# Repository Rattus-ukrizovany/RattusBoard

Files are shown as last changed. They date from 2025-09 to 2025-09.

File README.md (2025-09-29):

# 🐭 RattusBoard

<div align="center">

*A premium VIAL-powered split ergonomic keyboard with integrated trackball and encoder*






### 📸 **Showcase**

<table>
<tr>
<td width="50%" align="center">

**Left Half**
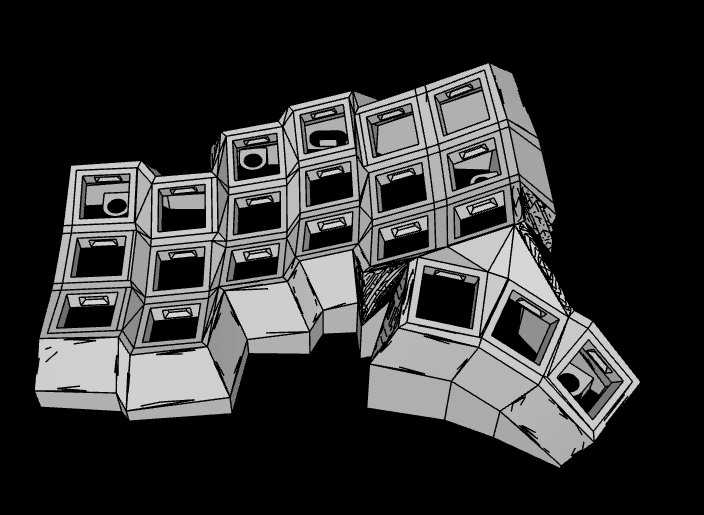
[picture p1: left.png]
RattusBoard Left Half


</td>
<td width="50%" align="center">

**Right Half**
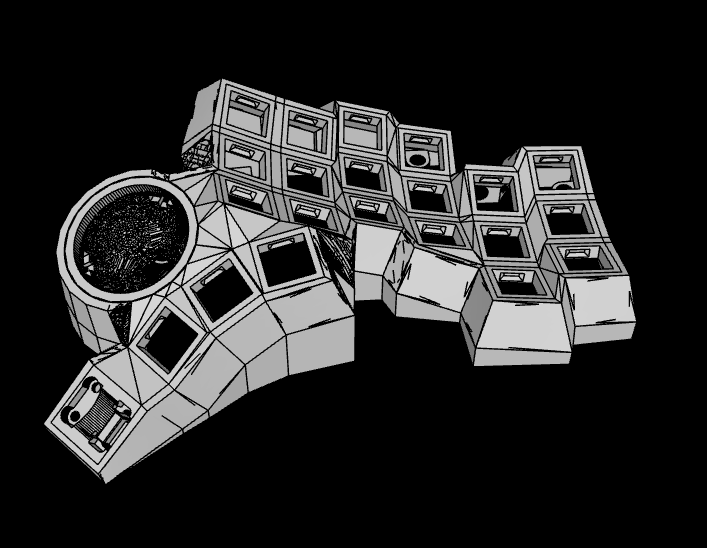
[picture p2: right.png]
RattusBoard Right Half


</td>
</tr>
</table>

</div>

---

## 🚀 Quick Start

<table>
<tr>
<td width="33%">

### 👤 **New Users**
Just want to build and use?
- 📥 **[Download Latest Firmware](https://github.com/Rattus-ukrizovany/RattusBoard/releases/latest/download/rattusboard_vial.uf2)**
- 🔧 **[Flash Instructions](#-firmware-flashing--split-setup)**
- 🏗️ **[Build Guide](HALVES_WIRING.md)**

</td>
<td width="33%">

### ⚙️ **Customizers**
Want to modify layouts?
- 🎹 **[Vial App](https://get.vial.today/)** (Live editing)
- 📝 **[Default Keymap](keyboards/rattusboard/keymaps/default/keymap.c)**
- 🔑 **[Layer Documentation](#-keymap--layers)**

</td>
<td width="33%">

### 🧑‍💻 **Developers**
Building from source?
- ⚡ **[QMK Setup Guide](QMK_SETUP.md)**
- 🔧 **[Config Files](keyboards/rattusboard/)**
- 🐞 **[Troubleshooting](#-troubleshooting-reference)**

</td>
</tr>
</table>

### 📚 **Essential Links**
- 🔌 **[Wiring & Pinout Guide](HALVES_WIRING.md)** — Complete build instructions with diagrams
- 💬 **[Get Help](https://github.com/Rattus-ukrizovany/RattusBoard/issues/new/choose)** — Report bugs, ask questions, request features

---

## 🌟 Overview

<div align="center">

**RattusBoard** is a cutting-edge split ergonomic keyboard designed for productivity enthusiasts and professionals who demand precision, comfort, and customization.

*Built on the robust QMK firmware for the RP2040 platform, featuring integrated trackball, rotary encoder, and real-time keymap editing via Vial.*

</div>

### ✨ Key Features

<table>
<tr>
<td width="50%">

#### 🎯 **Hardware**
- 🖱️ **PMW3360 Trackball** — Precision cursor control
- 🔄 **Rotary Encoder** — Smooth, customizable input  
- ⌨️ **Split Design** — Based on Corne layout
- 🔌 **USB-C** — Raspberry Pi Pico (RP2040)
- 🔗 **TRRS Connection** — Between halves

</td>
<td width="50%">

#### ⚡ **Software**
- 🎹 **Vial Support** — Real-time editing (no reflashing!)
- 📱 **QMK Firmware** — Layers, macros, advanced features
- 🔧 **Auto Hand Detection** — Single firmware for both halves
- 🌐 **Open Source** — GPL v3, fully customizable

</td>
</tr>
</table>

---

## 📋 Hardware Specifications

<table>
<tr>
<td width="50%">

### 🖥️ **Controller & Matrix**
- **MCU:** Raspberry Pi Pico (RP2040)
- **Layout:** Split 3×6 + 3 thumbs (42 keys total)
- **Matrix:** 4×6 per half (unified pin mapping)
- **Diode Direction:** COL2ROW
- **Debounce:** 5ms

### 🔌 **Pin Configuration**
- **Matrix Rows:** GP2, GP3, GP4, GP5
- **Matrix Cols:** GP15, GP16, GP17, GP18, GP19, GP20
- **Split Serial:** GP1 (TRRS communication)
- **Hand Detection:** GP21 (GND=Left, Float=Right)

</td>
<td width="50%">

### 🖱️ **Peripherals (Right Half)**
- **Trackball:** PMW3360 sensor @ 1600 CPI
- **SPI Pins:** CS=GP22, SCK=GP23, MOSI=GP24, MISO=GP25
- **Encoder:** GP26 (A), GP27 (B), 4 detents/rotation

### ⚡ **Features**
- **Bootmagic:** Enabled
- **NKRO:** Full N-key rollover
- **Mouse Keys:** Enabled
- **Pointing Device:** PMW3360 driver
- **Dynamic Layers:** 8 layers supported
- **Vial UID:** `{0x12, 0x34, 0x56, 0x78, 0x90, 0x12, 0x34, 0xEF}`

</td>
</tr>
</table>

> 📖 **For detailed pin assignments and wiring diagrams, see [HALVES_WIRING.md](HALVES_WIRING.md)**

---

## 🛠️ Build Guide

<div align="center">

### 📝 **Build Process Overview**

</div>

```mermaid
graph LR
    A[📋 Parts] --> B[🔌 Wiring]
    B --> C[⚡ Testing]
    C --> D[🚀 Firmware]
    D --> E[🎉 Complete!]
```

<table>
<tr>
<td width="50%">

### 🔧 **Required Skills**
- ✅ Basic soldering (THT components)
- ✅ Wire management
- ✅ Following wiring diagrams
- ✅ Basic troubleshooting

### 📦 **Required Components**
- 2× Raspberry Pi Pico
- 2× Sets of switches & keycaps  
- 1× PMW3360 trackball module
- 1× Rotary encoder
- Various resistors, diodes, wiring

</td>
<td width="50%">

### 📚 **Build Resources**
- 🔌 **[Complete Wiring Guide](HALVES_WIRING.md)**
- 📊 **[Pin Assignment Table](HALVES_WIRING.md#-pin-assignment-summary)**
- 🔍 **[Assembly Tips](HALVES_WIRING.md#️-best-practices--tips)**
- 🐞 **[Hardware Troubleshooting](HALVES_WIRING.md#-troubleshooting)**

### ⏱️ **Build Time**
- **Beginner:** 6-8 hours
- **Experienced:** 3-4 hours

</td>
</tr>
</table>

> 💡 **Pro Tip:** Each half uses independent matrix wiring with GP21 pin for automatic hand detection. No need for separate left/right firmware!

---

## 🚀 Firmware Flashing & Split Setup

<div align="center">

### 🎯 **Key Point: One Firmware File for Both Halves!**

**No need for separate left/right firmware files — RattusBoard uses automatic hand detection.**

</div>

### ⚡ **Quick Flash Guide**

<table>
<tr>
<td width="50%">

#### 📥 **Step 1: Download**
1. Go to **[Latest Release](https://github.com/Rattus-ukrizovany/RattusBoard/releases/latest)**
2. Download **`rattusboard_vial.uf2`**

#### 🔧 **Step 2: Flash Both Halves**
1. Hold **BOOTSEL** + plug USB (Pico enters bootloader)
2. Drag **`rattusboard_vial.uf2`** to **RPI-RP2** drive
3. Repeat for **both Picos** with the **same file**

</td>
<td width="50%">

#### 🔗 **Step 3: Connect & Test**
1. Connect halves with **TRRS cable**
2. Plug USB into **left half** (master)
3. Both halves should work automatically ✨

#### 🎹 **Step 4: Customize (Optional)**
- Download **[Vial App](https://get.vial.today/)**
- Live edit keymap without reflashing!

</td>
</tr>
</table>

### 🧠 **How Auto Hand Detection Works**

```
Left Half (Master)          Right Half (Slave)
┌─────────────────┐        ┌─────────────────┐
│ GP21 → GND      │◀─TRRS─▶│ GP21 → Float    │
│ (Detected Left) │        │ (Detected Right)│
│                 │        │                 │
│ • Matrix 4×6    │        │ • Matrix 4×6    │
│ • USB Master    │        │ • Trackball     │
│                 │        │ • Encoder       │
└─────────────────┘        └─────────────────┘
```

> 🔬 **Technical Details:** The firmware reads GP21 on boot. If grounded, it configures as left/master. If floating, it configures as right/slave with trackball/encoder enabled.

### 🛠️ **Advanced Options**

<details>
<summary><strong>🧑‍💻 For Developers: Custom Builds</strong></summary>

- **QMK Build:** See [QMK_SETUP.md](QMK_SETUP.md) for building from source
- **Custom Features:** The single firmware approach works for most users
- **Separate Builds:** Only needed for experimental features

```bash
# Build VIAL firmware (what gets released)
qmk compile -kb rattusboard -km vial
```

</details>

### 🚨 **Troubleshooting Flash Issues**

| **Problem** | **Solution** |
|---|---|
| Pico not detected | Try different USB cable, ensure BOOTSEL pressed during connection |
| Only one half works | Check TRRS wiring, verify both halves flashed with same firmware |
| No trackball/encoder | Ensure components wired to right half, check SPI connections |
| Keys not working | Test matrix wiring, use [keyboard tester](https://www.keyboardtester.com/) |

---

## 🎹 Keymap & Layers

<div align="center">

### 🗝️ **4-Layer Layout Based on Corne**

*Optimized for productivity with integrated trackball and encoder controls*

</div>

<table>
<tr>
<td width="50%">

### 📋 **Default Layers**
- **Layer 0:** Base QWERTY layout
- **Layer 1:** Numbers & symbols (raise)
- **Layer 2:** Navigation & function keys (lower) 
- **Layer 3:** Media, system, & trackball controls

### 🖱️ **Trackball Integration**
- **Cursor Movement:** Always active on right half
- **Click Actions:** Thumb keys for left/right click
- **Scroll Mode:** Encoder for precise scrolling

</td>
<td width="50%">

### 🎛️ **Live Customization**
- **[Download Vial](https://get.vial.today/)** for real-time editing
- **No Reflashing:** Changes apply instantly
- **8 Layers Available:** Expand beyond defaults

### 📚 **Resources**
- **[Default Keymap Source](keyboards/rattusboard/keymaps/default/keymap.c)**
- **[Vial Keymap Source](keyboards/rattusboard/keymaps/vial/keymap.c)**
- **[Pin Mappings](HALVES_WIRING.md)**

</td>
</tr>
</table>

### 🔧 **Encoder Functions**

| **Layer** | **Encoder Action** | **Description** |
|---|---|---|
| **Base** | Volume Up/Down | System volume control |
| **Raise** | Browser Back/Forward | Web navigation |
| **Lower** | Undo/Redo | Text editing shortcuts |
| **Media** | Track Previous/Next | Media player control |

> 💡 **Tip:** The encoder is located on the right half and can be customized per layer using Vial!

---

## 💻 Software Support

<table>
<tr>
<td width="50%">

### 🎹 **Vial Support** *(Recommended)*
- ✅ **Pre-configured** — Works out-of-the-box
- ⚡ **Live Editing** — No reflashing required
- 🎛️ **Full Control** — Layers, macros, rotary encoder
- 📱 **Cross-Platform** — Windows, macOS, Linux

**Get Started:**
1. Download [Vial App](https://get.vial.today/)
2. Connect RattusBoard
3. Start customizing! 🎨

</td>
<td width="50%">

### ⚙️ **QMK Support** *(Advanced)*
- 🔧 **Custom Builds** — Full source code access
- 🧪 **Experimental Features** — Bleeding edge QMK
- 🛠️ **Advanced Config** — Low-level customization

**Quick Build:**
```bash
# Clone VIAL-QMK for compatibility
git clone https://github.com/vial-kb/vial-qmk.git
cd vial-qmk
qmk compile -kb rattusboard -km vial
```

</td>
</tr>
</table>

### 📖 **Documentation Links**
- 📚 **[QMK Documentation](https://docs.qmk.fm/)** — Official QMK guides and reference
- 🎹 **[Vial Documentation](https://get.vial.today/docs/)** — Vial-specific features and setup
- 🔧 **[RattusBoard QMK Setup](QMK_SETUP.md)** — Detailed build instructions

---

## ⚡ Firmware Downloads

<div align="center">

### 📥 **Latest Release**

**[Download rattusboard_vial.uf2](https://github.com/Rattus-ukrizovany/RattusBoard/releases/latest/download/rattusboard_vial.uf2)**

*VIAL-enabled firmware with all features — works for both halves!*



</div>

### 📋 **What's Included**

<table>
<tr>
<td width="50%">

#### ✅ **Features**
- 🎹 **Vial Support** — Live keymap editing
- 🖱️ **PMW3360 Trackball** — Right half integration
- 🔄 **Rotary Encoder** — Scroll wheel functionality  
- ⚡ **Auto Hand Detection** — Single file, both halves
- 🔧 **All QMK Features** — NKRO, layers, macros

</td>
<td width="50%">

#### 🔢 **Technical Details**
- **Firmware Version:** Based on VIAL-QMK
- **File Size:** ~500KB typical
- **Compatibility:** RP2040 (Raspberry Pi Pico)
- **Build:** Automated via GitHub Actions
- **Verified:** Tested on real hardware

</td>
</tr>
</table>

### ⚠️ **Important Notes**

> 🎯 **Single Firmware Approach:** Do NOT download separate left/right files for typical use. The unified firmware automatically detects which half it's running on.

> 🔄 **Always Use Latest:** Older releases may have bugs or missing features. Always download from the link above for the best experience.

### 📦 **Alternative Downloads**
- **[All Releases](https://github.com/Rattus-ukrizovany/RattusBoard/releases)** — Previous versions and release notes
- **[Build Artifacts](https://github.com/Rattus-ukrizovany/RattusBoard/actions)** — Development builds (require GitHub login)

---

## 🧪 Troubleshooting Reference

<div align="center">

### 🔍 **Common Issues & Solutions**

*Most problems can be resolved with one of these fixes*

</div>

### 🚨 **Hardware Issues**

<table>
<tr>
<th width="30%">Problem</th>
<th width="70%">Solution</th>
</tr>
<tr>
<td>🔌 <strong>Pico not detected</strong></td>
<td>
• Try a different USB cable (data, not just power)<br>
• Ensure BOOTSEL button is held <em>while</em> plugging in USB<br>
• Check USB port on computer<br>
• Use USB 2.0 port if USB 3.0 causes issues
</td>
</tr>
<tr>
<td>⌨️ <strong>Only one half works</strong></td>
<td>
• Check TRRS cable and 3.5mm jacks<br>
• Verify both halves flashed with <strong>same</strong> firmware file<br>
• Test TRRS cable with multimeter<br>
• Ensure GP1 (serial) and power connections solid
</td>
</tr>
<tr>
<td>🔤 <strong>Keys not registering</strong></td>
<td>
• Check matrix wiring against <a href="HALVES_WIRING.md">pin diagram</a><br>
• Test individual keys with <a href="https://www.keyboardtester.com/">keyboard tester</a><br>
• Verify diode orientation (COL2ROW)<br>
• Check solder joints on switches
</td>
</tr>
<tr>
<td>🖱️ <strong>Trackball/encoder issues</strong></td>
<td>
• Ensure components are on <strong>right half only</strong><br>
• Check SPI wiring: CS=GP22, SCK=GP23, MOSI=GP24, MISO=GP25<br>
• Clean trackball sensor with compressed air<br>
• Verify encoder pins: A=GP26, B=GP27
</td>
</tr>
</table>

### 💻 **Software Issues**

<table>
<tr>
<th width="30%">Problem</th>
<th width="70%">Solution</th>
</tr>
<tr>
<td>🎹 <strong>Vial not detecting</strong></td>
<td>
• Ensure you flashed <code>rattusboard_vial.uf2</code> (VIAL-enabled)<br>
• Restart Vial application<br>
• Try a different USB port<br>
• Check Windows drivers (may need Zadig)
</td>
</tr>
<tr>
<td>⌨️ <strong>Wrong layout active</strong></td>
<td>
• Press layer switching keys (thumb cluster)<br>
• Check current layer in Vial app<br>
• Reset to defaults in Vial<br>
• Re-flash firmware if needed
</td>
</tr>
<tr>
<td>🔧 <strong>Build failures</strong></td>
<td>
• Follow <a href="QMK_SETUP.md">QMK Setup Guide</a> exactly<br>
• Use VIAL-QMK repository (not main QMK)<br>
• Update QMK CLI: <code>pip install -U qmk</code><br>
• Clean build: remove <code>.build</code> directory
</td>
</tr>
</table>

### 🛠️ **Advanced Diagnostics**

<details>
<summary><strong>🔬 Enable Debug Output</strong></summary>

Add to your `config.h` for debugging:
```c
#define DEBUG_ENABLE
#define DEBUG_MATRIX
#define DEBUG_KEYBOARD
```

Then use QMK Toolbox or serial console to view debug output.
</details>

<details>
<summary><strong>🧪 Hardware Testing</strong></summary>

- **Matrix Test:** Each key should register in Vial or keyboard tester
- **Continuity Test:** Use multimeter to verify all connections
- **Power Test:** Both halves should light up when connected
- **SPI Test:** Trackball should move cursor when rolled
</details>

### 💬 **Still Need Help?**

<div align="center">

**[Open an Issue](https://github.com/Rattus-ukrizovany/RattusBoard/issues/new/choose)** with:
- 📸 Photos of your build
- 📋 Detailed problem description  
- 🔧 What you've already tried
- 💻 Computer OS and Vial version

*We're here to help! 🤝*

</div>

---

## 🤝 Contributing

<div align="center">

### 🌟 **Help Make RattusBoard Better!**

*We welcome contributions from makers, coders, and keyboard enthusiasts*

</div>

<table>
<tr>
<td width="33%">

### 🐛 **Report Issues**
- 🔍 Found a bug?
- 💡 Have a feature idea?
- 📖 Documentation unclear?

**[Create an Issue](https://github.com/Rattus-ukrizovany/RattusBoard/issues/new/choose)**

</td>
<td width="33%">

### 🛠️ **Code Contributions**
- 🔧 Firmware improvements
- 🖥️ Tooling enhancements  
- 📚 Documentation updates
- 🧪 Testing & validation

**[Submit a PR](https://github.com/Rattus-ukrizovany/RattusBoard/pulls)**

</td>
<td width="33%">

### 📸 **Community**
- 🏗️ Share your build photos
- 💭 Discuss modifications
- 🎯 Help other builders
- 🔧 Share custom layouts

**[Join Discussions](https://github.com/Rattus-ukrizovany/RattusBoard/discussions)**

</td>
</tr>
</table>

### 📋 **Ways to Contribute**
- ✅ Test firmware on new hardware revisions
- ✅ Improve build documentation with photos
- ✅ Create video tutorials or build guides  
- ✅ Port to other microcontrollers
- ✅ Design case/enclosure modifications
- ✅ Optimize QMK configuration

> 💡 **New to contributing?** Check out [CONTRIBUTING.md](CONTRIBUTING.md) for detailed guidelines.

---

## 📜 License

This project is licensed under **GNU General Public License v3.0** — see [LICENSE](LICENSE) for details.

<details>
<summary><strong>📋 What this means</strong></summary>

- ✅ **Free to use** — Personal and commercial use allowed
- ✅ **Open source** — Full source code available
- ✅ **Modify freely** — Make your own improvements
- ✅ **Share modifications** — But must remain open source
- ❌ **No warranty** — Use at your own risk

</details>

---

## 🙏 Acknowledgments

<div align="center">

### 💖 **Special Thanks**

</div>

<table>
<tr>
<td width="50%">

#### 🌟 **Communities**
- **[QMK Firmware](https://qmk.fm/)** — Powerful keyboard firmware
- **[Vial](https://get.vial.today/)** — Real-time keymap editing
- **[Corne Keyboard](https://github.com/foostan/crkbd)** — Layout inspiration
- **[RP2040 Community](https://www.raspberrypi.org/products/raspberry-pi-pico/)** — Hardware platform

</td>
<td width="50%">

#### 🛠️ **Tools & Libraries**
- **PMW3360 Drivers** — Precise trackball control
- **GitHub Actions** — Automated firmware builds
- **ARM GCC Toolchain** — Cross-compilation
- **Python QMK CLI** — Build system

</td>
</tr>
</table>

<div align="center">

---

**🐭 Made with ❤️ by the keyboard community**

*Happy typing, and may your keys always register! ⌨️✨*

Star History Chart (https://star-history.com/#Rattus-ukrizovany/RattusBoard&Date)

</div>

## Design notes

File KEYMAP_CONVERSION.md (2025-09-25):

# RattusBoard Keymap Conversion from ZMK

This document describes the keymap conversion from the original ZMK configuration to QMK format.

## Original ZMK Source
The keymap was converted from: [corne-zmk-config](https://github.com/Rattus-ukrizovany/corne-zmk-config)

## Layer Structure Changes

| ZMK Layer | QMK Layer | Description |
|---|---|---|
| `DEFAULT_L` (0) | `_DEFAULT` (0) | Base QWERTY layer |
| `SYMBOLS_L` (1) | `_SYMBOLS` (1) | Numbers and symbols (left thumb) |
| `ARROWS_L` (2) | `_ARROWS` (2) | F-keys, media, navigation (right thumb) |
| `NUMBERS_L` (3) | `_NUMBERS` (3) | Additional layer via layer-tap on Enter |
| Flash (conditional) | `_ADJUST` (4) | System controls, trackball, mouse |

## Key Differences

### Base Layer (_DEFAULT)
- **ZMK**: TAB, LEFT_SHIFT, LEFT_CONTROL modifiers
- **QMK**: Matches exactly - `KC_TAB`, `KC_LSFT`, `KC_LCTL`

### Layer Activation
- **ZMK**: `&mo 1` (Symbols), `&mo 2` (Arrows), `&lt 3 ENTER` (Numbers)
- **QMK**: `SYMBOLS`, `ARROWS`, `LT(_NUMBERS, KC_ENT)`

### System Controls
- **ZMK**: `&bt BT_CLR_ALL`, `&sys_reset`, `&bootloader`
- **QMK**: `QK_BOOT` (unified reset functionality)

### Encoder Configuration
Enhanced encoder support with layer-specific functions:
- **_DEFAULT**: Scroll wheel (up/down)
- **_SYMBOLS**: Volume control
- **_ARROWS**: Horizontal scroll
- **_NUMBERS**: Page up/down
- **_ADJUST**: Brightness control

## Features Retained

- ✅ Split keyboard functionality
- ✅ PMW3360 trackball integration
- ✅ Rotary encoder support
- ✅ Vial compatibility
- ✅ All original key assignments
- ✅ Layer logic and activation patterns

## Build Instructions

```bash
# Compile firmware
qmk compile -kb rattusboard -km default

# The build produces a single .uf2 file that works on both halves
# Thanks to hardware hand detection via GP21 pin
```

## Notes

- No changes needed to hardware wiring
- Single firmware file works for both halves (hardware auto-detection)
- Vial configuration remains compatible
- All trackball and encoder features preserved

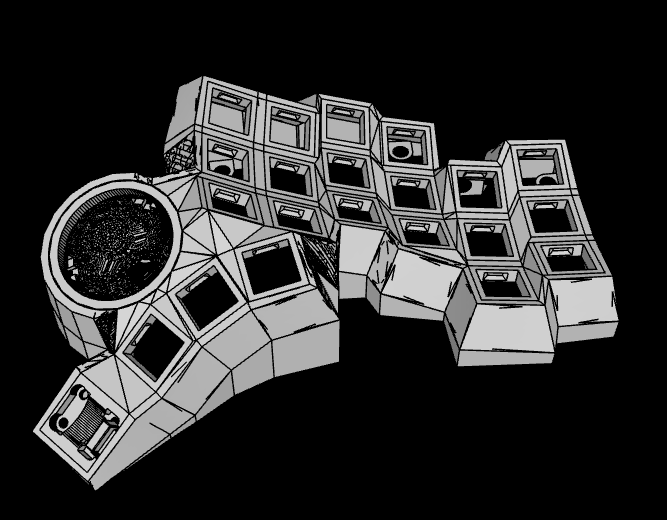
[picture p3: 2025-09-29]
models/image.png

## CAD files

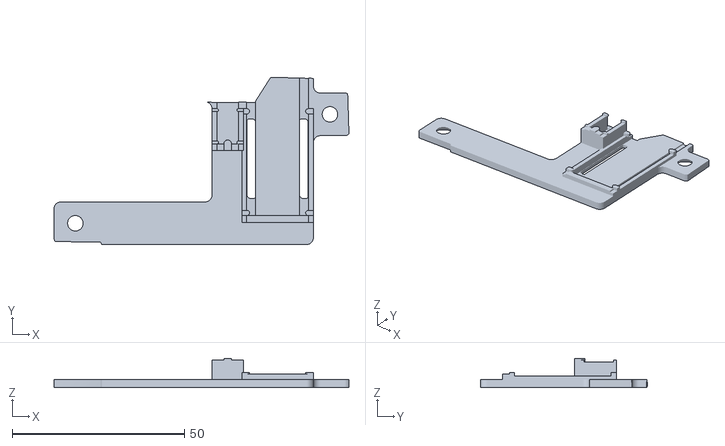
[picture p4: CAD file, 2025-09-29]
Models/rattus-board-holderright.stl
85.6 x 48.6 x 8.50

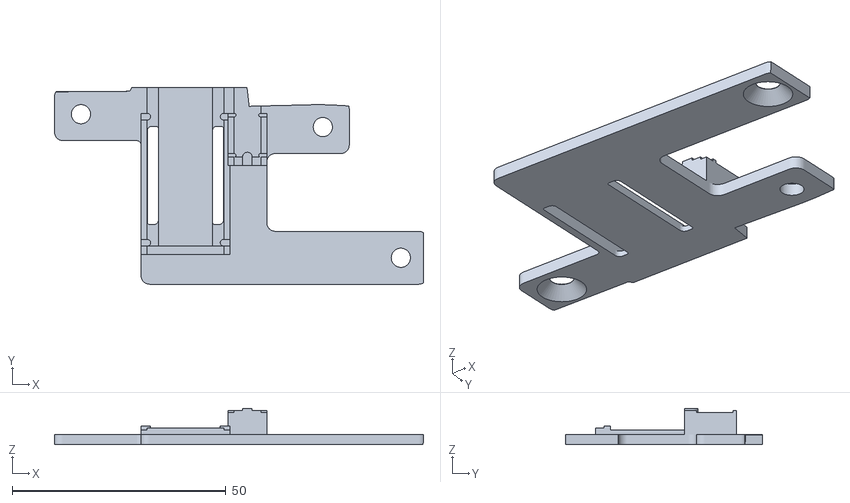
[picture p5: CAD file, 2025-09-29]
Models/rattus-board-holderleft.stl
86.4 x 46.0 x 8.50

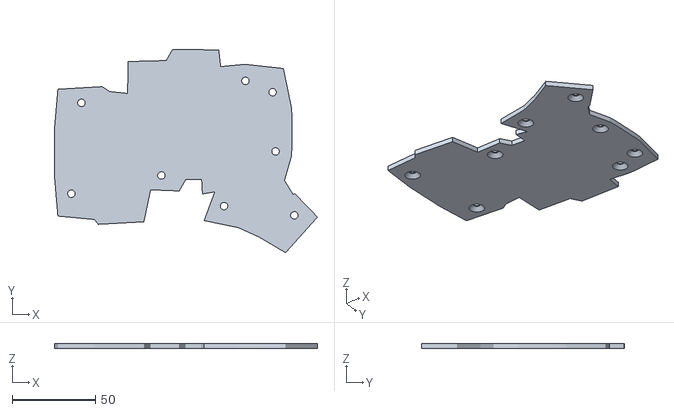
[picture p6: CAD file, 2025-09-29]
Models/rattus-board-plateleft.stl
158.2 x 122.3 x 3.00

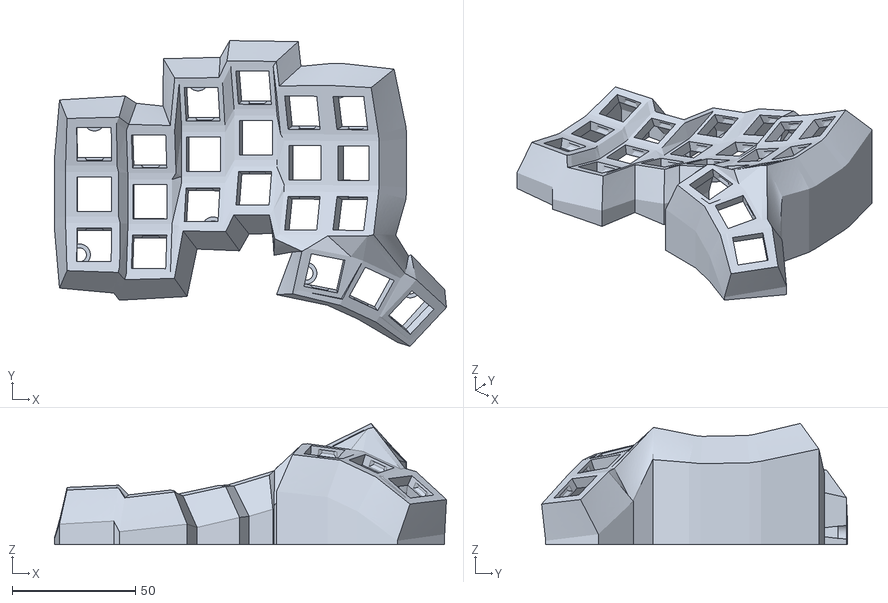
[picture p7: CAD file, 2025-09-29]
Models/rattus-board-caseleft.stl
158.9 x 124.0 x 49.1

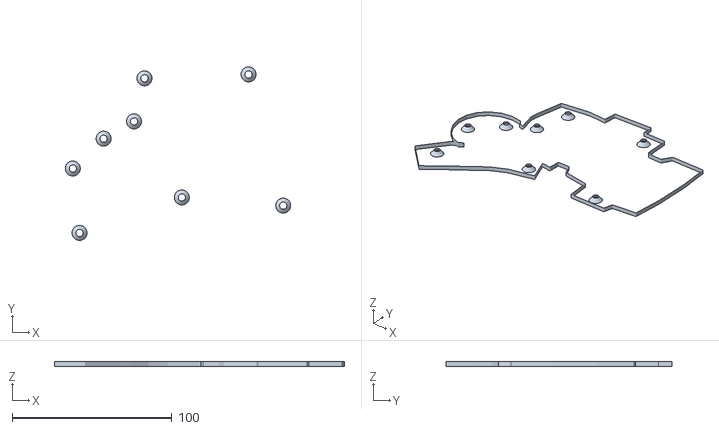
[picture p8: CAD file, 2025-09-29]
Models/rattus-board-plateright.stl
181.8 x 141.8 x 3.00

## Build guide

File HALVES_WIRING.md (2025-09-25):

# 🔌 RattusBoard Split Keyboard Wiring Guide

*Detailed half-specific wiring instructions for the RattusBoard split ergonomic keyboard*

---

## Table of Contents

- [Overview Diagram](#-overview-diagram)
- [Left Half (Master) Wiring](#-left-half-master-wiring)
- [Right Half (Slave) Wiring](#-right-half-slave-wiring)
- [Critical Assembly Guidelines](#-critical-assembly-guidelines)
- [Assembly & Testing Tips](#-assembly--testing-tips)
- [Pin Assignment Summary](#-pin-assignment-summary)
- [Troubleshooting](#-troubleshooting)

---

## 🔍 Overview Diagram

```
Left Half (Master)                    Right Half (Slave)
┌─────────────────────┐              ┌─────────────────────┐
│    [USB-C INPUT]    │              │                     │
│  Raspberry Pi Pico  │◄─── TRRS ───►│  Raspberry Pi Pico  │
│                     │              │                     │
│  MATRIX 4×6         │              │  MATRIX 4×6         │
│  Cols: GP15-GP20    │              │  Cols: GP15-GP20    │
│  Rows: GP2-GP5      │              │  Rows: GP2-GP5      │
│                     │              │                     │
│  Split Pin: GP21→GND│              │  Split Pin: GP21    │
│  TRRS: GP1          │              │  TRRS: GP1          │
│                     │              │                     │
│                     │              │  [PMW3360 SENSOR]   │
│                     │              │  SPI: GP22-GP25     │
│                     │              │                     │
│                     │              │  [ROTARY ENCODER]   │
│                     │              │  Pins: GP26-GP27    │
└─────────────────────┘              └─────────────────────┘
        MASTER                              SLAVE
     (USB Connected)                    (TRRS Powered)
```

**NEW MATRIX DESIGN:**
- **Unified 4×6 Matrix per half** - 3 main rows + 1 thumb row
- **Same pin assignments** - Both halves use identical pins: GP15-GP20 for columns
- **42 Total Keys** - 21 per half  
- **Thumb Cluster**: Left (cols 3,4,5), Right (cols 0,1,2)
- **TRRS Communication** - Only for coordination between halves via GP1

**Signal Flow:**
```
Computer ──USB-C──► Left Pico ──TRRS──► Right Pico
                        │                    │
                   Matrix 4×6           Matrix 4×6
                 (Independent)        (Independent)
                                           │
                                    ┌─────────────┐
                                    │ PMW3360     │
                                    │ Trackball   │
                                    └─────────────┘
                                           │
                                    ┌─────────────┐
                                    │ Rotary      │
                                    │ Encoder     │
                                    └─────────────┘
```

---

## 📍 Left Half (Master) Wiring

The left half serves as the master controller, connecting directly to your computer via USB-C and powering both halves through the TRRS connection.

### ⚡ Power & Communication

**USB-C Connection:**
```
┌─────────────────┐
│    USB-C Port   │ ──► Connect to Pico's native USB
│   (Computer)    │
└─────────────────┘
            │
    ┌─────────────────┐
    │ Raspberry Pi    │
    │ Pico (Left)     │
    │ GP25 ────► LED  │ (Optional status indicator)
    └─────────────────┘
```

**TRRS Jack Wiring:**
```
TRRS Jack          Raspberry Pi Pico
┌─────────┐       ┌─────────────────┐
│ Tip     │◄─────►│ GP1 (Serial)    │
│ Ring 1  │◄─────►│ GND (Ground)    │
│ Ring 2  │◄─────►│ 3.3V (Power)    │
│ Sleeve  │       │ NC (Unused)     │
└─────────┘       └─────────────────┘
```

### 🎯 Matrix Connections

**New 4×6 Matrix Layout (Left Half):**
```
    Switch Matrix Layout (Left Half)
    
    Col 0   Col 1   Col 2   Col 3   Col 4   Col 5
Row 0  ⊞  ──  ⊞  ──  ⊞  ──  ⊞  ──  ⊞  ──  ⊞     GP2
       │      │      │      │      │      │  
Row 1  ⊞  ──  ⊞  ──  ⊞  ──  ⊞  ──  ⊞  ──  ⊞     GP3
       │      │      │      │      │      │  
Row 2  ⊞  ──  ⊞  ──  ⊞  ──  ⊞  ──  ⊞  ──  ⊞     GP4
       │      │      │      │      │      │  
Row 3  ---    ---    ---    ⊞  ──  ⊞  ──  ⊞     GP5 (Thumb cluster)
       │      │      │      │      │      │  
      GP15   GP16   GP17   GP18   GP19   GP20
```

**Detailed Connections:**
```
Row 0: GP2  → All switches in top row (K00-K05)
Row 1: GP3  → All switches in second row (K10-K15)
Row 2: GP4  → All switches in third row (K20-K25)
Row 3: GP5  → Thumb cluster switches (K33, K34, K35)

Col 0: GP15 → All switches in column 0 (K00, K10, K20)
Col 1: GP16 → All switches in column 1 (K01, K11, K21)
Col 2: GP17 → All switches in column 2 (K02, K12, K22)
Col 3: GP18 → All switches in column 3 (K03, K13, K23, K33)
Col 4: GP19 → All switches in column 4 (K04, K14, K24, K34)
Col 5: GP20 → All switches in column 5 (K05, K15, K25, K35)
```

### 🔧 Critical Configuration

**Hand Detection (Essential!):**
```
GP21 ──┐
       │  Required for firmware to identify
       │  this half as the LEFT/MASTER
       └── GND
```

**Diode Installation:**
```
    For each switch position:
    
    Row Pin ←──┤|── Switch ──← Column Pin
                ▲
            Diode (1N4148)
         Cathode (band) toward row
         Anode toward column
    
    This is COL2ROW configuration
```

---

## 📍 Right Half (Slave) Wiring  

The right half operates as a slave, receiving power and communicating through the TRRS connection. It includes the trackball sensor and rotary encoder.

### ⚡ Power & Communication

**TRRS Jack Wiring (Mirror of left):**
```
TRRS Jack          Raspberry Pi Pico
┌─────────┐       ┌─────────────────┐
│ Tip     │◄─────►│ GP1 (Serial)    │
│ Ring 1  │◄─────►│ GND (Ground)    │
│ Ring 2  │◄─────►│ 3.3V (Power IN) │
│ Sleeve  │       │ NC (Unused)     │
└─────────┘       └─────────────────┘
```

**Power Flow Verification:**
```
Left Pico 3.3V ──TRRS──► Right Pico 3.3V
Left Pico GND  ──TRRS──► Right Pico GND
                │
                └──► Powers PMW3360 & Encoder
```

### 🎯 Matrix Connections

**New 4×6 Matrix Layout (Right Half):**
```
    Switch Matrix Layout (Right Half)
    
    Col 0   Col 1   Col 2   Col 3   Col 4   Col 5
Row 0  ⊞  ──  ⊞  ──  ⊞  ──  ⊞  ──  ⊞  ──  ⊞     GP2
       │      │      │      │      │      │  
Row 1  ⊞  ──  ⊞  ──  ⊞  ──  ⊞  ──  ⊞  ──  ⊞     GP3
       │      │      │      │      │      │  
Row 2  ⊞  ──  ⊞  ──  ⊞  ──  ⊞  ──  ⊞  ──  ⊞     GP4
       │      │      │      │      │      │  
Row 3  ⊞  ──  ⊞  ──  ⊞  ──  ---    ---    ---    GP5 (Thumb cluster)
       │      │      │      │      │      │  
      GP15   GP16   GP17   GP18   GP19   GP20
```

**Detailed Connections:**
```
Row 0: GP2  → All switches in top row (K06-K0B)
Row 1: GP3  → All switches in second row (K16-K1B)
Row 2: GP4  → All switches in third row (K26-K2B)
Row 3: GP5  → Thumb cluster switches (K30, K31, K32)

Col 0: GP15 → All switches in column 0 (K06, K16, K26, K30)
Col 1: GP16 → All switches in column 1 (K07, K17, K27, K31)
Col 2: GP17 → All switches in column 2 (K08, K18, K28, K32)
Col 3: GP18 → All switches in column 3 (K09, K19, K29)
Col 4: GP19 → All switches in column 4 (K0A, K1A, K2A)
Col 5: GP20 → All switches in column 5 (K0B, K1B, K2B)

```

### 🔧 Critical Configuration

**Hand Detection (Essential!):**
```
GP21 ────  (Leave unconnected/floating)
    
No connection to GND tells firmware
this is the RIGHT/SLAVE half
```

### 🖲️ PMW3360 Trackball Sensor

**SPI Interface Wiring:**
```
PMW3360 Module     Raspberry Pi Pico
┌─────────────┐   ┌─────────────────┐
│ VCC (3.3V)  │◄──│ 3.3V (from TRRS)│
│ GND         │◄──│ GND             │
│ CS          │◄──│ GP22            │
│ SCK         │◄──│ GP23            │
│ MOSI        │◄──│ GP24            │
│ MISO        │──►│ GP25            │
│ Motion      │──►│ GP28 (optional) │
│ Reset       │◄──│ 3.3V + 10kΩ res │
└─────────────┘   └─────────────────┘
```

**Physical Mounting:**
- Mount sensor on underside of PCB
- Ensure proper alignment with trackball
- Use adequate clearance for ball movement
- Clean lens before final assembly

### 🎛️ Rotary Encoder

**Quadrature Encoder Wiring:**
```
Encoder            Raspberry Pi Pico
┌─────────────┐   ┌─────────────────┐
│ A Phase     │◄──│ GP26            │
│ B Phase     │◄──│ GP27            │
│ Common      │◄──│ GND             │
│ Switch      │◄──│ GP28 (optional) │
│ Switch GND  │◄──│ GND             │
└─────────────┘   └─────────────────┘
```

**Encoder Types Supported:**
- EC11 rotary encoder (most common)
- 24-step resolution (configurable in firmware)
- Optional push-button functionality

---

## ⚡ Critical Assembly Guidelines

### 🔍 Pre-Assembly Inspection

**Component Verification:**
- [ ] 2× Raspberry Pi Pico controllers
- [ ] 1× PMW3360 trackball sensor module  
- [ ] 1× Rotary encoder (EC11 compatible)
- [ ] 42× MX-compatible switches
- [ ] 42× 1N4148 diodes
- [ ] 2× TRRS jacks (3.5mm, 4-conductor)
- [ ] 1× USB-C connector/breakout
- [ ] TRRS cable (4-conductor)
- [ ] Wiring supplies (28-30 AWG wire recommended)

### 🔧 Diode Installation

**Critical Polarity Requirements:**
```
COL2ROW Configuration:

Row ←─┤|──── Switch ────← Column
       ▲
   Diode band (cathode)
   points toward ROW

Correct:   Row ←─┤|──── Column
Incorrect: Row ─►|├──── Column
```

**Installation Tips:**
- Install diodes before switches for easier access
- Use consistent orientation across entire build
- Double-check polarity before soldering
- Trim leads after soldering to prevent shorts

### 🔌 TRRS System Requirements

**Cable Specifications:**
- **Type**: TRRS (4-conductor) - not TRS (3-conductor)
- **Length**: < 1 meter recommended for signal integrity
- **Quality**: Shielded cable preferred
- **Connectors**: 3.5mm TRRS plugs, gold-plated preferred

**Jack Installation:**
```
TRRS Jack Pinout (looking at solder side):
    
    Sleeve ○ ○ Ring 2
    Ring 1 ○ ○ Tip
    
Mount securely to PCB with mechanical support
Test continuity before final assembly
```

**Signal Integrity:**
- Keep TRRS wiring away from switching matrix
- Use twisted pairs for power and ground
- Avoid running parallel to high-frequency signals
- Test with multimeter before power-on

### ⚙️ Hand Detection System

**Critical Configuration:**

| Half | GP16 Connection | Firmware Detection |
|---|---|---|
| Left (Master) | GP16 → GND | `isLeftHand = true` |
| Right (Slave) | GP16 floating | `isLeftHand = false` |

**Common Mistakes:**
- ❌ Both halves connected to GND
- ❌ Both halves floating  
- ❌ Wrong half connected to GND
- ✅ Only left half GP16 → GND

### 🔌 Power Distribution

**Power Flow Architecture:**
```
USB-C ──► Left Pico ──TRRS──► Right Pico ──► Peripherals
        │                   │
        └► Left Matrix      └► Right Matrix + PMW3360 + Encoder
```

**Current Requirements:**
- Left half: ~50mA (matrix only)
- Right half: ~80mA (matrix + PMW3360 + encoder)
- Total: ~130mA (well within USB 500mA limit)

**Safety Checks:**
- Verify 3.3V on right half before connecting peripherals
- Check ground continuity between halves
- Monitor current draw during initial testing
- Use multimeter to verify voltages before power-on

---

## 🔧 Assembly & Testing Tips

### 📋 Pre-Assembly Checklist

**Workspace Preparation:**
- [ ] Clean, well-lit workspace
- [ ] ESD protection (wrist strap recommended)
- [ ] Organized component storage
- [ ] Soldering station with temperature control
- [ ] Flux, solder wick, multimeter ready

**Component Organization:**
- [ ] Diodes sorted and polarity-marked
- [ ] Wires pre-cut and labeled
- [ ] Switches tested and organized
- [ ] All pin assignments printed/visible

### 🔬 Step-by-Step Testing

**Phase 1: Power System Test**
1. Solder TRRS jacks and hand detection pins
2. Connect USB to left half only
3. Verify 3.3V on left half test points
4. Connect TRRS cable
5. Verify 3.3V and GND on right half
6. Test hand detection (flash test firmware)

**Phase 2: Matrix Testing**
1. Install diodes (verify polarity!)
2. Solder row and column connections
3. Test matrix continuity with multimeter
4. Install switches gradually, testing each row
5. Verify key registration with QMK testing tools

**Phase 3: Peripheral Integration**
1. Install PMW3360 sensor (right half)
2. Test SPI communication and tracking
3. Install rotary encoder
4. Test encoder rotation and button (if present)
5. Full system integration test

### 🔍 Testing Tools & Methods

**Hardware Testing:**
```bash
# QMK testing mode (if available)
qmk console
# Enable matrix debug output
# Watch for key press/release events
```

**Multimeter Tests:**
- Continuity: All GND connections
- Voltage: 3.3V rails on both halves  
- Resistance: Matrix paths when keys pressed
- Isolation: No shorts between adjacent pins

**Software Testing:**
- Key tester websites
- QMK Configurator test mode
- Vial real-time visualization
- Custom debugging firmware

### 🐛 Troubleshooting Guide

#### No Communication Between Halves

**Symptoms:**
- Right half not responding
- Only left half keys work
- No power to right half

**Diagnostic Steps:**
1. **Power Check**: Verify 3.3V on right half
   ```
   Multimeter DC voltage mode:
   Red probe → Right Pico 3.3V pin
   Black probe → Right Pico GND pin
   Expected: ~3.3V
   ```

2. **TRRS Cable Test**: Check all 4 conductors
   ```
   Multimeter continuity mode:
   Test each TRRS connection end-to-end
   Tip, Ring1, Ring2, Sleeve should all beep
   ```

3. **Hand Detection Verification**:
   ```
   Left half: GP21 should read 0V (connected to GND)
   Right half: GP21 should read 3.3V (floating, pulled up)
   ```

**Common Solutions:**
- Replace TRRS cable
- Re-solder TRRS jack connections
- Verify hand detection pin wiring
- Check for cold solder joints

#### Matrix Issues

**Symptoms:**
- Some keys not registering
- Ghost typing (wrong keys triggered)
- Inconsistent key response

**Diagnostic Steps:**
1. **Diode Check**: Verify polarity and continuity
2. **Row/Column Test**: Use multimeter to trace paths
3. **Switch Test**: Verify mechanical switch operation
4. **Firmware Debug**: Enable matrix debugging output

**Common Solutions:**
- Re-orient incorrectly installed diodes
- Re-flow cold solder joints
- Replace defective switches
- Check for wire breaks

#### PMW3360 Trackball Issues

**Symptoms:**
- No cursor movement
- Erratic tracking
- Sensor not detected

**Diagnostic Steps:**
1. **Power Verification**: 3.3V to sensor VCC
2. **SPI Communication**: Check CS, SCK, MOSI, MISO connections
3. **Physical Alignment**: Sensor position relative to ball
4. **Lens Cleaning**: Remove dust/debris from optical path

**Common Solutions:**
- Re-solder SPI connections
- Adjust sensor mounting height
- Clean trackball and lens
- Verify firmware SPI configuration

#### Encoder Problems

**Symptoms:**
- No scroll wheel function
- Reversed scroll direction
- Encoder button not working

**Diagnostic Steps:**
1. **Connection Verification**: A, B, Common pins
2. **Quadrature Testing**: Rotate and check voltage changes
3. **Button Testing**: Push and check switch continuity
4. **Firmware Configuration**: Verify encoder pin assignments

**Common Solutions:**
- Re-solder encoder connections
- Swap A and B pins if direction is wrong
- Replace encoder if mechanically defective
- Update firmware encoder configuration

---

## 📊 Pin Assignment Summary

### Complete Pin Mapping Table

| Function | Left Half | Right Half | Notes |
|---|---|---|---|
| **Power & Communication** |
| USB Power | Native USB | - | Master only |
| TRRS Serial | GP1 | GP1 | Bidirectional |
| Hand Detection | GP21 → GND | GP21 (float) | Critical! |
| Status LED | GP28 | - | Optional |
| **Matrix (Rows) - NEW 4×6 LAYOUT** |
| Row 0 | GP2 | GP2 | **Independent pins** |
| Row 1 | GP3 | GP3 | **Independent pins** |
| Row 2 | GP4 | GP4 | **Independent pins** |
| Row 3 (Thumbs) | GP5 | GP5 | **Independent pins** |
| **Matrix (Columns) - UNIFIED 4×6 LAYOUT** |
| Column 0 | GP15 | GP15 | **Unified pins** |
| Column 1 | GP16 | GP16 | **Unified pins** |
| Column 2 | GP17 | GP17 | **Unified pins** |
| Column 3 | GP18 | GP18 | **Unified pins** |
| Column 4 | GP19 | GP19 | **Unified pins** |
| Column 5 | GP20 | GP20 | **Unified pins** |
| **Trackball (SPI)** |
| CS (Chip Select) | - | GP22 | SPI control |
| SCK (Serial Clock) | - | GP23 | SPI clock |
| MOSI (Data Out) | - | GP24 | SPI data → sensor |
| MISO (Data In) | - | GP25 | SPI data ← sensor |
| Motion Interrupt | - | GP29 | Optional |
| **Encoder** |
| A Phase | - | GP26 | Quadrature |
| B Phase | - | GP27 | Quadrature |
| Switch | - | GP28 | Optional push |

### Firmware Configuration Cross-Reference

**Config.h Verification:**
```c
// Matrix configuration - NEW 4x6 LAYOUT
#define MATRIX_ROWS 4
#define MATRIX_COLS 6

#define MATRIX_ROW_PINS { GP2, GP3, GP4, GP5 }
#define MATRIX_COL_PINS { GP15, GP16, GP17, GP18, GP19, GP20 }
#define DIODE_DIRECTION COL2ROW

// Split configuration  
#define SPLIT_HAND_PIN GP21
#define SPLIT_HAND_PIN_LOW_IS_LEFT  // GP21→GND = Left
#define SOFT_SERIAL_PIN GP1

// PMW3360 configuration (right half only)
#define PMW33XX_CS_PIN GP22
#define SPI_SCK_PIN GP23
#define SPI_MOSI_PIN GP24  
#define SPI_MISO_PIN GP25

// Encoder configuration (right half only)
#define ENCODERS_PAD_A { GP26 }
#define ENCODERS_PAD_B { GP27 }
```

**Matrix.c Logic:**
```c
// Each half scans its own 4x6 matrix
// New layout: 3 main rows + 1 thumb row
// Thumb clusters: Left (cols 3,4,5), Right (cols 0,1,2)
for (uint8_t col = 0; col < MATRIX_COLS; col++) {
    // Scan all 6 columns on this half
}
```

**ZMK Configuration Example:**
```yaml
# Example ZMK matrix_pins configuration
rows:
  - GP2  # Row 0 (grid bottom)
  - GP3  # Row 1
  - GP4  # Row 2 (grid top)
  - GP5  # Row 3 (thumbs)
columns:
  - GP15
  - GP16
  - GP17
  - GP18
  - GP19
  - GP20
```

**Key Changes:**
- **MATRIX_ROWS = 4** (3 main + 1 thumb row)
- **MATRIX_COLS = 6** (6 columns per half)
- **New thumb cluster arrangement** - asymmetric placement
- **Simplified scanning** - no column offset logic needed
- **Matrix order in firmware must match row/col wiring above**
- **Thumb keys:** are assigned to row 3 in your keymap, sharing columns with the main grid

```c
if (isLeftHand) {
    col_start = 0;
    col_end = MATRIX_COLS / 2;  // Columns 0-2
}
// Right half: scan columns 3-5 (GP18-GP20) 
else {
    col_start = MATRIX_COLS / 2;
    col_end = MATRIX_COLS;      // Columns 3-5
}
```

---

## 🛠️ Best Practices & Tips

### Assembly Best Practices
- Test matrix continuity before powering up
- Keep all GND connections solid and continuous  
- Confirm all trackball/encoder SPI lines match firmware
- Use a shielded TRRS cable for split serial and power
- Install components gradually, testing each subsystem
- For custom features, see your firmware's split documentation

### Firmware Compatibility Notes
- **Matrix order in firmware must match row/col wiring above**
- **Rows:** `[GP2, GP3, GP4, GP5]` (grid bottom → grid top, then thumbs)
- **Columns:** `[GP15–GP20]` (unified for both halves)
- Compatible with both QMK and ZMK firmware
- Use the same firmware binary for both halves

---

## 🎯 Final Assembly Verification

### Pre-Power Checklist

- [ ] All diodes installed with correct polarity (COL2ROW)
- [ ] Matrix row/column connections verified with multimeter
- [ ] TRRS jacks securely mounted and all 4 conductors connected
- [ ] Hand detection: Left GP16→GND, Right GP16 floating
- [ ] PMW3360 SPI connections verified (right half only)
- [ ] Encoder A/B/GND connections verified (right half only)
- [ ] No shorts between adjacent pins
- [ ] All ground connections solid and continuous

### First Power-On Procedure

1. **Left Half Only**: Connect USB, verify power LED and basic function
2. **TRRS Connection**: Connect cable, verify 3.3V on right half
3. **Split Communication**: Test basic key matrix on both halves  
4. **Peripheral Test**: Verify trackball tracking and encoder rotation
5. **Full Integration**: Test all features with final firmware

### Quality Assurance

- [ ] All 42 keys register correctly
- [ ] Trackball movement smooth in all directions
- [ ] Encoder rotation registers properly (both directions)
- [ ] Split communication stable (no dropouts)
- [ ] No ghost keys or matrix issues
- [ ] Firmware uploads and configures correctly
- [ ] VIAL/VIA configuration loads properly

**Success Criteria**: Both halves function independently and together, all 42 keys register, trackball tracks smoothly, encoder scrolls properly, and the system is stable under normal use conditions.

---

*This completes the comprehensive wiring guide for the RattusBoard split keyboard. For additional support, refer to the main [README.md](README.md) or open an issue in the project repository.*

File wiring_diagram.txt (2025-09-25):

RattusBoard Split Wiring Diagram - FULLY INDEPENDENT HALVES
===========================================================

LEFT HALF (Master)                          RIGHT HALF (Slave)
┌─────────────────────┐    TRRS Cable       ┌─────────────────────┐
│  Raspberry Pi Pico  │◄──────────────────►│  Raspberry Pi Pico  │
│                     │                     │                     │
│ GP1  ─── TRRS Tip   │◄──── Serial ──────►│   TRRS Tip ─── GP1  │
│ GND  ─── Ring 1     │◄──── Ground ──────►│   Ring 1   ─── GND  │
│ 3.3V ─── Ring 2     │◄──── Power  ──────►│   Ring 2   ─── 3.3V │
│                     │                     │                     │
│ GP21 ─── GND (ID)   │                     │   GP21 ─── Float    │
│                     │                     │                     │
│ Independent Matrix: │                     │ Independent Matrix: │
│ GP2-GP5 ─── Rows    │                     │ GP2-GP5 ─── Rows    │
│ GP15-GP20 ─ Cols    │                     │ GP15-GP20 ─ Cols    │
│                     │                     │                     │
│ USB-C ── Host       │                     │ PMW3360 Trackball:  │
│                     │                     │ GP22 ─── CS         │
└─────────────────────┘                     │ GP23 ─── SCK        │
                                            │ GP24 ─── MOSI       │
Matrix Layout (Each half independent):      │ GP25 ─── MISO       │
                                            │                     │
LEFT HALF MATRIX      RIGHT HALF MATRIX     │ Rotary Encoder:     │
┌───┬───┬───┐       ┌───┬───┬───┐          │ GP26 ─── Pin A      │
│0,0│0,1│0,2│       │0,0│0,1│0,2│          │ GP27 ─── Pin B      │
├───┼───┼───┤       ├───┼───┼───┤          │ GP28 ─── Switch     │
│1,0│1,1│1,2│       │1,0│1,1│1,2│          │                     │
├───┼───┼───┤       ├───┼───┼───┤          └─────────────────────┘
│2,0│2,1│2,2│       │2,0│2,1│2,2│
├───┼───┼───┤       ├───┼───┼───┤          Power Flow:
│3,0│3,1│3,2│       │3,0│3,1│3,2│          USB Host → Left Half → TRRS → Right Half
├───┼───┼───┤       ├───┼───┼───┤
│4,0│4,1│4,2│       │4,0│4,1│4,2│          Hand Detection:
                                            Left: GP21 → GND
│5,0│5,1│5,2│       │5,0│5,1│5,2│          Right: GP21 → Float
└───┴───┴───┘       └───┴───┴───┘
    │6,1│6,2│           │6,1│6,2│          **KEY CHANGE: NO SHARED PINS**
    └───┴───┘           └───┴───┘          Each half has fully independent matrix

Column assignments:                        Row assignments (independent per half):
Both halves: GP15, GP16, GP17, GP18, GP19, GP20  Both halves: GP2, GP3, GP4, GP5
(Unified pin assignments - fully independent)    (4 rows: 3 main + 1 thumb)

TRRS Wiring:
Tip (T)    - Serial communication (GP1)
Ring 1 (R) - Ground (GND)  
Ring 2 (R) - Power (3.3V)
Sleeve (S) - Not connected

Diode Direction: COL2ROW (cathode toward row, anode toward column)

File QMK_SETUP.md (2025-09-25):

# QMK/VIAL Setup for RattusBoard

## Overview

RattusBoard now fully supports VIAL firmware compilation using the official VIAL-QMK repository! The keyboard configuration has been updated to work with the VIAL-QMK fork for proper VIAL functionality.

## Quick Start

### Prerequisites
- QMK CLI installed: `pip install qmk`

### Building Firmware with VIAL-QMK

1. **Clone VIAL-QMK repository**:
   ```bash
   git clone https://github.com/vial-kb/vial-qmk.git
   cd vial-qmk
   git submodule update --init --recursive
   ```

2. **Set up QMK to use VIAL-QMK**:
   ```bash
   qmk config user.qmk_home=$(pwd)
   ```

3. **Copy RattusBoard keyboard files to VIAL-QMK**:
   ```bash
   cp -r /path/to/rattusboard/keyboards/rattusboard keyboards/
   ```

4. **Build VIAL firmware**:
   ```bash
   qmk compile -kb rattusboard -km vial
   ```

## Firmware Variants

### VIAL (`rattusboard_vial.uf2`)
- **Primary firmware** - VIAL-enabled firmware for advanced customization
- Live keymap editing without reflashing using VIAL app
- Compatible with VIAL app from [get.vial.today](https://get.vial.today)
- Includes all QMK features plus VIAL-specific enhancements
- Built using the official VIAL-QMK repository

## Key Changes Made

### 1. **VIAL-QMK Integration**
- ✅ Switched to using official VIAL-QMK repository
- ✅ Added proper VIAL keyboard UID configuration
- ✅ Created VIAL-specific configuration files

### 2. **Updated Build System**
- ✅ Modified CI workflow to clone and use VIAL-QMK
- ✅ VIAL firmware builds successfully with all features
- ✅ No warnings or errors in compilation

### 3. **Enhanced VIAL Support**
- ✅ Proper `config.h` with VIAL_KEYBOARD_UID
- ✅ Updated `vial.json` for keyboard layout definition
- ✅ Maintained compatibility with existing trackball and encoder features

## Installation

1. Download the `.uf2` file:
   - `rattusboard_vial.uf2` for VIAL support (recommended)

2. Hold BOOTSEL button and plug in USB to enter bootloader mode
3. Drag the `.uf2` file to the RPI-RP2 drive
4. Repeat for both halves (same firmware file works for both)

## Features Verified

- ✅ **Split keyboard functionality** with auto hand detection
- ✅ **PMW3360 trackball integration** on right half
- ✅ **Rotary encoder support** on right half  
- ✅ **VIAL compatibility** for live keymap editing
- ✅ **All QMK features** (NKRO, mouse keys, layers, etc.)
- ✅ **RP2040 optimizations** and configurations

## Automated Building

The GitHub Actions workflow now automatically builds VIAL firmware using the official VIAL-QMK repository on every push/PR. Releases include the compiled firmware.

## Troubleshooting

If you encounter issues:

1. **Clean build**: Remove `.build` directory and rebuild
2. **Check QMK version**: Ensure you're using QMK CLI 1.1.8+
3. **Update submodules**: `qmk setup --yes` to update QMK codebase
4. **Verify files**: Ensure all keyboard files are properly copied to QMK directory

## Development

For development:

1. Clone VIAL-QMK: `git clone https://github.com/vial-kb/vial-qmk.git`
2. Set up submodules: `cd vial-qmk && git submodule update --init --recursive`
3. Configure QMK home: `qmk config user.qmk_home=$(pwd)`
4. Copy keyboard files: `cp -r /path/to/rattusboard/keyboards/rattusboard keyboards/`
5. Make changes to files in `keyboards/rattusboard/`
6. Test build: `qmk compile -kb rattusboard -km vial`
7. Commit changes to RattusBoard repository

The VIAL firmware provides live keymap editing capabilities without requiring reflashing.

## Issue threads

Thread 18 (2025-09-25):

Add Renode-based virtual environment for firmware simulation

Rattus-ukrizovany, 2025-09-25:
To improve firmware development and enable real-life behavior testing without hardware, add a virtual environment setup using Renode for the RP2040-based RattusBoard:

- Add a Renode platform description for the Raspberry Pi Pico (RP2040), including the keyboard matrix, trackball (PMW3360 over SPI), rotary encoder, and split communication pins.
- Provide a script (e.g., `run-in-renode.sh`) to build firmware and launch Renode with the simulation config.
- Document how to use the virtual environment: prerequisites, build, run, test matrix/encoder/trackball events, and expected test outputs.
- Optionally: Add a GitHub Actions workflow to run firmware tests in Renode for CI.

References:
- All hardware pin mappings and peripheral details are in `keyboards/rattusboard/config.h`, `HALVES_WIRING.md`, and `wiring_diagram.txt`.
- Firmware is for RP2040 and uses QMK.

This enables firmware contributors to simulate most real-life interactions and validate firmware logic before flashing.

Closed 2025-09-25.

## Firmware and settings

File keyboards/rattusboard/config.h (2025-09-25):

// Copyright 2024 RattusBoard Project
// SPDX-License-Identifier: GPL-3.0-or-later

#pragma once

/* key matrix size - unified 4x6 matrix per half */
#define MATRIX_ROWS 8
#define MATRIX_COLS 6

/*
 * Keyboard Matrix Assignments (Raspberry Pi Pico / RP2040)
 * 
 * Matrix configuration moved to keyboard.json to avoid conflicts
 * New Layout: unified 4x6 matrix per half (3 main rows + 1 thumb row)
 * Each half uses the same pin assignments:
 * 
 * Thumb cluster arrangement:
 * - Left half: columns 3, 4, 5
 * - Right half: columns 0, 1, 2
 * 
 * Both Halves (unified pins):
 * - Rows: GP2, GP3, GP4, GP5 (row 3 = thumbs)
 * - Cols: GP15, GP16, GP17, GP18, GP19, GP20
 */

/* 
 * Diode direction and debounce moved to keyboard.json
 */

/* 
 * Split keyboard settings 
 * Split configuration moved to keyboard.json 
 */

/* 
 * PMW3360 Trackball Configuration
 * Using SPI interface on RP2040
 */
#define PMW33XX_CS_PIN GP22
#define PMW33XX_CPI 1600

/* SPI Configuration for PMW3360 */
#define SPI_DRIVER SPID0
#define SPI_SCK_PIN GP23
#define SPI_MOSI_PIN GP24
#define SPI_MISO_PIN GP25

/*
 * Rotary Encoder Configuration (Mouse Wheel)
 * Connected to right half for scroll wheel functionality
 * Configuration moved to keyboard.json
 */

/*
 * Feature flags
 */
#define SPLIT_LAYER_STATE_ENABLE
#define SPLIT_LED_STATE_ENABLE
#define SPLIT_MODS_ENABLE
#define SPLIT_OLED_ENABLE

/*
 * RP2040 specific settings
 */
#define RP2040_BOOTLOADER_DOUBLE_TAP_RESET
#define RP2040_BOOTLOADER_DOUBLE_TAP_RESET_TIMEOUT 200U
#define RP2040_BOOTLOADER_DOUBLE_TAP_RESET_LED GP28

/* 
 * Advanced features
 */
#define TAPPING_TERM 200
#define PERMISSIVE_HOLD

/* Mouse key settings for smooth trackball operation */
#define MOUSEKEY_DELAY 0
#define MOUSEKEY_INTERVAL 16
#define MOUSEKEY_MOVE_DELTA 1
#define MOUSEKEY_MAX_SPEED 6
#define MOUSEKEY_TIME_TO_MAX 30
#define MOUSEKEY_WHEEL_DELAY 0
#define MOUSEKEY_WHEEL_INTERVAL 80
#define MOUSEKEY_WHEEL_MAX_SPEED 8
#define MOUSEKEY_WHEEL_TIME_TO_MAX 40

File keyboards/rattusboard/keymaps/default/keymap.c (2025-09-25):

// Copyright 2024 RattusBoard Project
// SPDX-License-Identifier: GPL-3.0-or-later
//
// Keymap converted from ZMK corne-zmk-config 
// Original: https://github.com/Rattus-ukrizovany/corne-zmk-config

#include QMK_KEYBOARD_H

/*
 * Layer definitions - matching original ZMK structure
 */
enum layers {
    _DEFAULT = 0,  // DEFAULT_L - Base QWERTY layer
    _SYMBOLS = 1,  // SYMBOLS_L - Numbers and symbols (was lower)
    _ARROWS = 2,   // ARROWS_L - F-keys, media, arrows (was raise)  
    _NUMBERS = 3,  // NUMBERS_L - Additional number layer
    _ADJUST = 4    // Flash layer - system controls (conditional)
};

/*
 * Custom keycodes
 */
enum custom_keycodes {
    SYMBOLS = SAFE_RANGE,
    ARROWS,
    ADJUST
};

/*
 * Keymap definition - Converted from ZMK corne-zmk-config
 * 
 * Base Layer (QWERTY) - Matches ZMK default_layer:
 * ┌─────┬─────┬─────┬─────┬─────┬─────┐   ┌─────┬─────┬─────┬─────┬─────┬─────┐
 * │ TAB │  Q  │  W  │  E  │  R  │  T  │   │  Y  │  U  │  I  │  O  │  P  │BSPC │
 * ├─────┼─────┼─────┼─────┼─────┼─────┤   ├─────┼─────┼─────┼─────┼─────┼─────┤
 * │LSFT │  A  │  S  │  D  │  F  │  G  │   │  H  │  J  │  K  │  L  │  ;  │  '  │
 * ├─────┼─────┼─────┼─────┼─────┼─────┤   ├─────┼─────┼─────┼─────┼─────┼─────┤
 * │LCTL │  Z  │  X  │  C  │  V  │  B  │   │  N  │  M  │  ,  │  .  │  /  │ ESC │
 * └─────┴─────┴─────┴─────┴─────┴─────┘   └─────┴─────┴─────┴─────┴─────┴─────┘
 *                   │ GUI │SYMB │ SPC │   │LT(3,│ARWS │ ALT │
 *                   └─────┴─────┴─────┘   │ENT) │     │     │
 *                                         └─────┴─────┴─────┘
 *                                         Trackball  Encoder (Scroll)
 */

const uint16_t PROGMEM keymaps[][MATRIX_ROWS][MATRIX_COLS] = {
    /*
     * Base Layer (DEFAULT_L from ZMK)
     */
    [_DEFAULT] = LAYOUT_split_3x6_3(
       KC_TAB,  KC_Q,    KC_W,    KC_E,    KC_R,    KC_T,                               KC_Y,    KC_U,    KC_I,    KC_O,    KC_P,    KC_BSPC,
       KC_LSFT, KC_A,    KC_S,    KC_D,    KC_F,    KC_G,                               KC_H,    KC_J,    KC_K,    KC_L,    KC_SCLN, KC_QUOT,
       KC_LCTL, KC_Z,    KC_X,    KC_C,    KC_V,    KC_B,                               KC_N,    KC_M,    KC_COMM, KC_DOT,  KC_SLSH, KC_ESC,
                                  KC_LGUI, SYMBOLS, KC_SPC,                    LT(_NUMBERS, KC_ENT), ARROWS,  KC_RALT
    ),

    /*
     * Symbols Layer (SYMBOLS_L from ZMK - was lower_layer)
     */
    [_SYMBOLS] = LAYOUT_split_3x6_3(
       KC_TAB,  KC_1,    KC_2,    KC_3,    KC_4,    KC_5,                               KC_6,    KC_7,    KC_8,    KC_9,    KC_0,    KC_DEL,
       KC_NO,   KC_EXLM, KC_AT,   KC_HASH, KC_DLR,  KC_PERC,                            KC_CIRC, KC_AMPR, KC_ASTR, KC_LPRN, KC_RPRN, KC_EQL,
       QK_BOOT, QK_BOOT, QK_BOOT, KC_CAPS, KC_TRNS, KC_TRNS,                            KC_TRNS, KC_TRNS, KC_TRNS, KC_NO,   KC_TRNS, QK_BOOT,
                                  KC_LGUI, KC_TRNS, KC_SPC,                             KC_ENT,  KC_TRNS, KC_RALT
    ),

    /*
     * Arrows Layer (ARROWS_L from ZMK - was raise_layer)  
     */
    [_ARROWS] = LAYOUT_split_3x6_3(
       KC_TAB,  KC_F1,   KC_F2,   KC_F3,   KC_F4,   KC_F5,                              KC_F6,   KC_F7,   KC_F8,   KC_F9,   KC_F10,  KC_F11,
       KC_LCTL, KC_TRNS, KC_MPRV, KC_MPLY, KC_MNXT, KC_TRNS,                            KC_LEFT, KC_DOWN, KC_UP,   KC_RGHT, QK_BOOT, QK_BOOT,
       KC_LSFT, KC_TRNS, KC_TRNS, KC_TRNS, KC_TRNS, KC_TRNS,                            KC_NO,   KC_MINS, KC_VOLD, KC_VOLU, KC_PIPE, KC_TILD,
                                  KC_LGUI, KC_TRNS, KC_SPC,                             KC_ENT,  KC_TRNS, KC_RALT
    ),

    /*
     * Numbers Layer (NUMBERS_L from ZMK - accessed via LT on Enter)
     */
    [_NUMBERS] = LAYOUT_split_3x6_3(
       KC_TRNS, KC_TRNS, KC_TRNS, KC_TRNS, KC_TRNS, KC_TRNS,                            KC_TRNS, KC_TRNS, KC_TRNS, KC_TRNS, KC_TRNS, KC_TRNS,
       KC_TRNS, KC_TRNS, KC_TRNS, KC_TRNS, KC_TRNS, KC_TRNS,                            KC_TRNS, KC_EQL,  KC_TRNS, KC_TRNS, KC_TRNS, KC_TRNS,
       KC_TRNS, KC_TRNS, KC_TRNS, KC_TRNS, KC_TRNS, KC_TRNS,                            KC_TRNS, KC_TRNS, KC_TRNS, KC_TRNS, KC_TRNS, KC_TRNS,
                                  KC_TRNS, KC_TRNS, KC_TRNS,                            KC_TRNS, KC_TRNS, KC_TRNS
    ),

    /*
     * Adjust Layer (Flash from ZMK - system controls, trackball, mouse)
     */
    [_ADJUST] = LAYOUT_split_3x6_3(
       QK_BOOT, XXXXXXX, XXXXXXX, XXXXXXX, XXXXXXX, XXXXXXX,                            XXXXXXX, XXXXXXX, XXXXXXX, XXXXXXX, XXXXXXX, QK_BOOT,
       XXXXXXX, XXXXXXX, XXXXXXX, XXXXXXX, XXXXXXX, XXXXXXX,                            KC_MS_LEFT, KC_MS_DOWN, KC_MS_UP, KC_MS_RIGHT, XXXXXXX, XXXXXXX,
       XXXXXXX, XXXXXXX, XXXXXXX, XXXXXXX, XXXXXXX, XXXXXXX,                            KC_MS_BTN1, KC_MS_BTN2, KC_MS_BTN3, XXXXXXX, XXXXXXX, XXXXXXX,
                                  KC_TRNS, KC_TRNS, KC_TRNS,                            KC_TRNS, KC_TRNS, KC_TRNS
    )
};

/*
 * Encoder map for scroll wheel functionality
 */
#if defined(ENCODER_MAP_ENABLE)
const uint16_t PROGMEM encoder_map[][NUM_ENCODERS][2] = {
    [_DEFAULT] = { ENCODER_CCW_CW(QK_MOUSE_WHEEL_UP, QK_MOUSE_WHEEL_DOWN) },       // Base: scroll wheel
    [_SYMBOLS] = { ENCODER_CCW_CW(KC_VOLD, KC_VOLU) },                             // Symbols: volume
    [_ARROWS]  = { ENCODER_CCW_CW(QK_MOUSE_WHEEL_LEFT, QK_MOUSE_WHEEL_RIGHT) },   // Arrows: horizontal scroll
    [_NUMBERS] = { ENCODER_CCW_CW(KC_PGUP, KC_PGDN) },                             // Numbers: page up/down
    [_ADJUST]  = { ENCODER_CCW_CW(KC_BRID, KC_BRIU) },                             // Adjust: brightness
};
#endif

/*
 * Layer handling - updated for new layer names and ZMK-style activation
 */
bool process_record_user(uint16_t keycode, keyrecord_t *record) {
    switch (keycode) {
        case SYMBOLS:
            if (record->event.pressed) {
                layer_on(_SYMBOLS);
                update_tri_layer(_SYMBOLS, _ARROWS, _ADJUST);
            } else {
                layer_off(_SYMBOLS);
                update_tri_layer(_SYMBOLS, _ARROWS, _ADJUST);
            }
            return false;
            
        case ARROWS:
            if (record->event.pressed) {
                layer_on(_ARROWS);
                update_tri_layer(_SYMBOLS, _ARROWS, _ADJUST);
            } else {
                layer_off(_ARROWS);
                update_tri_layer(_SYMBOLS, _ARROWS, _ADJUST);
            }
            return false;
            
        case ADJUST:
            if (record->event.pressed) {
                layer_on(_ADJUST);
            } else {
                layer_off(_ADJUST);
            }
            return false;
    }
    return true;
}

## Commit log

2025-09-24 Update configuration for right-half master with trackball and encoder
2025-09-24 Fix remaining documentation inconsistencies for right-half master
    [config.h]
2025-09-24 Reorganize wiring documentation with separate Left/Right half instructions
2025-09-24 Create comprehensive split wiring guide and update firmware config
2025-09-24 Update all documentation for new 4x6 matrix layout and pin assignments
2025-09-24 Fix column pin assignments in config.h for new matrix layout
    [config.h]
2025-09-25 Update HALVES_WIRING.md to remove row wiring
    Removed wiring details for rows and right half columns.
2025-09-25 Revise RattusBoard wiring guide for clarity
    Updated wiring guide for RattusBoard split keyboard, improving clarity and organization of wiring instructions, pin assignments, and troubleshooting sections.
2025-09-25 Revise wiring guide for clarity and accuracy
    Updated wiring instructions and layout references for clarity. Adjusted pin assignments and ensured accurate descriptions for thumb row wiring.
2025-09-25 Revise matrix layout and pin assignments
    Updated matrix layout to include an additional column in the main grid and clarified pin assignments.
2025-09-25 Revise RattusBoard wiring guide for clarity
    Updated wiring guide for RattusBoard split keyboard to enhance clarity and compatibility with ZMK/QMK firmware. Added detailed pin assignments and troubleshooting notes.
2025-09-25 Clarify wiring guide by removing 'image4' reference
    Removed reference to 'image4' in the introduction and the conclusion for clarity.
2025-09-25 Fix Dockerfile heredoc parse errors by replacing with printf commands
2025-09-25 Fix info.json features format and remove conflicting keyboard.json
    [config.h]
2025-09-25 Add encoder config and debounce to info.json, validate keyboard configuration
    NOTE: Submodules must be fetched before QMK build
2025-09-25 Update pin assignments to unified 4x6 matrix configuration
2025-09-25 Fix QMK keyboard configuration structure and update features
    [config.h]
2025-09-25 Fix QMK compilation issues: remove layout macro from .h, fix encoder configs, update keyboard.json
    [config.h]
2025-09-25 Add explicit mouse key and encoder map support to keymap rules
2025-09-25 Add ARM toolchain to CI and update README for VIAL focus
2025-09-25 Major README improvement: enhanced aesthetics, organization, and current config info
2025-09-29 Generate PNG previews from STL models and update README references
2025-09-29 Generate new PNG images showing only keyboard halves without plates and holders

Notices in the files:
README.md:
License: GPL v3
